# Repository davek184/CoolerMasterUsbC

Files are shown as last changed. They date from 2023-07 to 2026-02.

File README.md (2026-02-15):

# Cooler Master Novatouch Daughterboard USB-C
USB-C Daughterboard for Cooler Master Novatouch. Fits in the stock case without any changes.  Also fits Norbatouch, Masterkeys Pro S & Rapid-i.

Update 2026: This version is suprior but can be difficult to obtain so built an [alternative DIY option](https://github.com/davek184/Coolermaster-USB-C-remix)

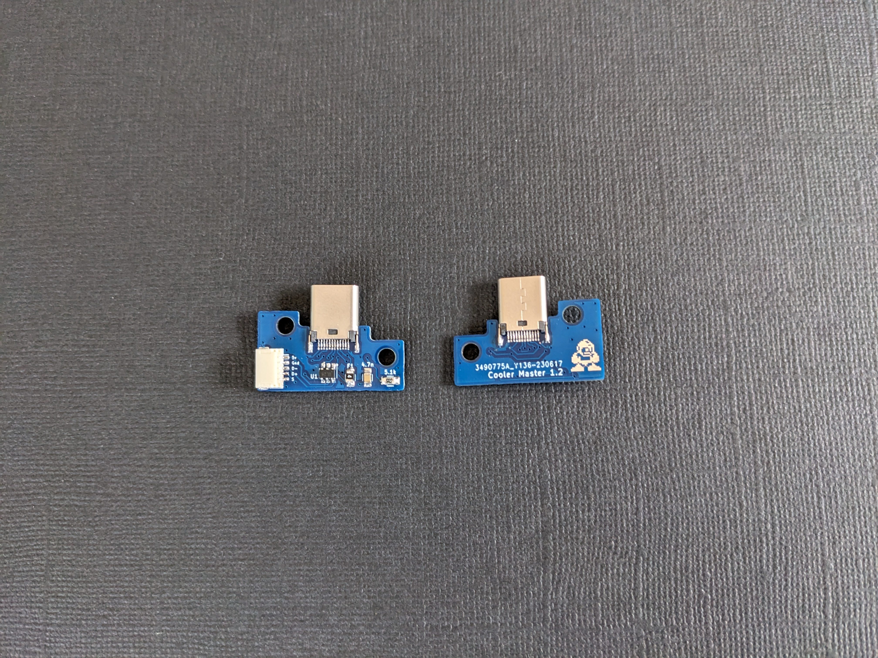
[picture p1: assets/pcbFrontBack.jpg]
PCB2


## Disclaimers
* Norbatouch compatible if using 2 m3 nuts as washers.
* Use at your own risk
* This will only give USB-C connection for the keyboard. Programmability requires a custom full PCB.

# Cable
* JST SH to PH cable
* 5 pin
* 150mm long
* Good start cable
  * https://www.aliexpress.us/item/3256804552474270.html
  * "Same Direction" so only 2 wires need to be swapped after receiving. Plug in SH (small end) first. swap the D- and D+ wire on the PH end.
  * See pinout diagram
    
## Novatouch Pinout  
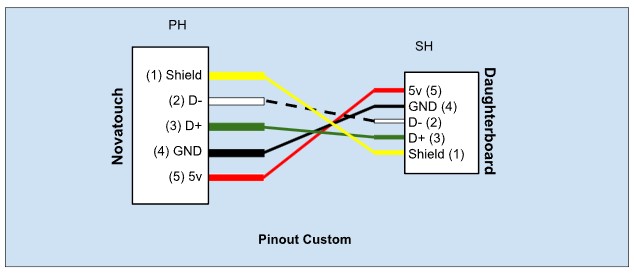
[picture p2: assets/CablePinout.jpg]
Cable

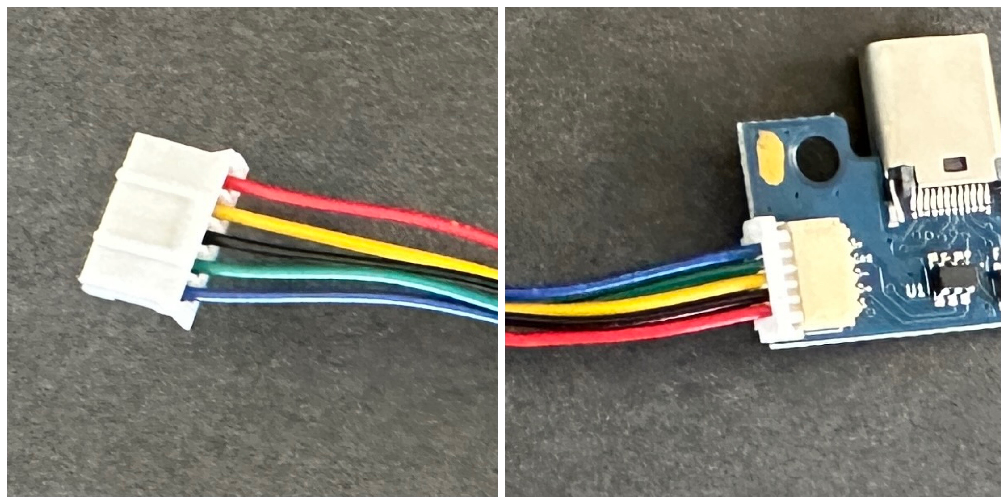
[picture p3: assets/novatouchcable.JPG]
Novatouch


## Masterkeys Pro S Pinout
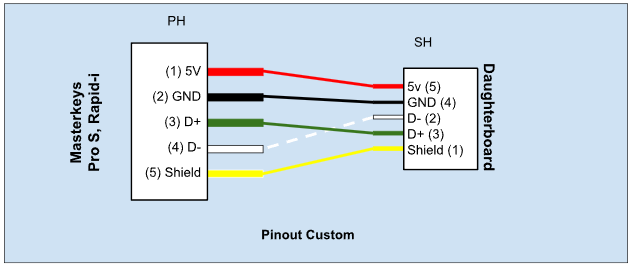
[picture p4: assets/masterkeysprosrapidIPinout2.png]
CablePros

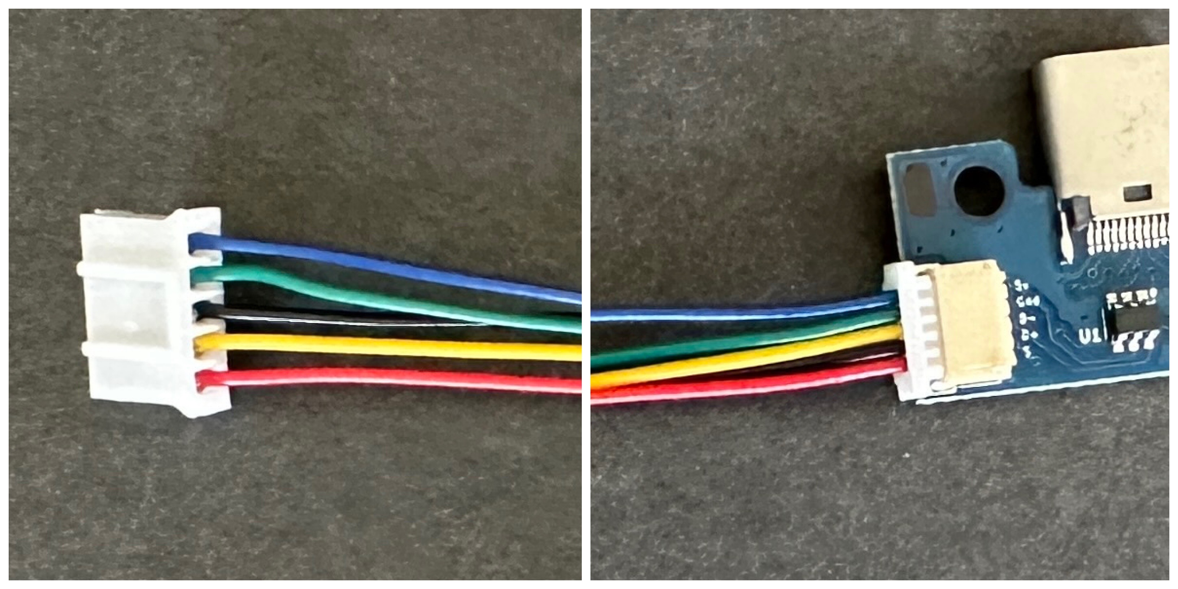
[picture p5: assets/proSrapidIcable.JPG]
ProS


## Rapid-i Pinout
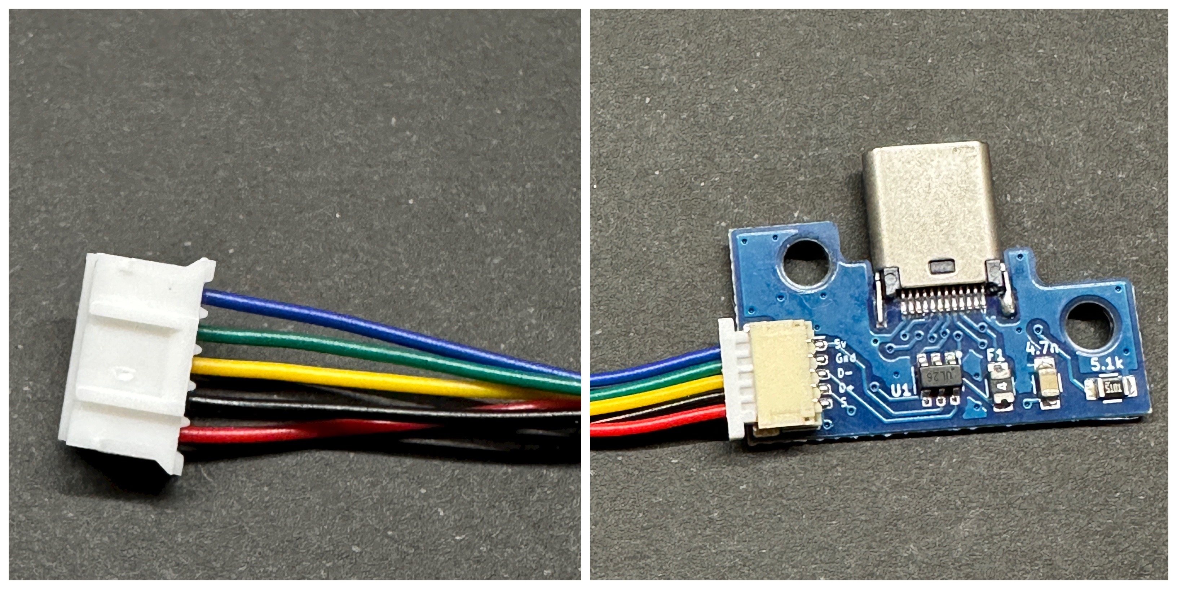
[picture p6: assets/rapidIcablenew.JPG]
Rapid-I


# Recommended Hardware

* M2 x 4mm wafer head screw/laptop screw. For mounting CMDB into stock Novatouch case. https://www.aliexpress.us/item/3256801240948974.html 
* M3 x 0.5mm 6mm hex screw, 3mm hex nut. For mounting CMDB into Norbatouch. Add o-ring or washer if still sitting too low in port opening.
* [Alternative 3d print riser](/assets/Coolermaster%20USB%20C%20Riser.stl)

# Installation Photos

<details>
 <summary>Stock Novatouch</summary>
 
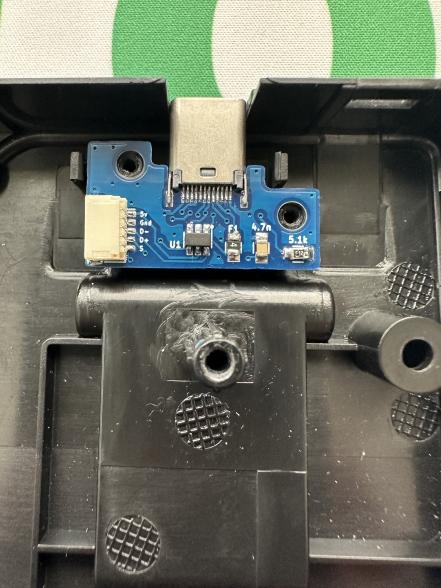
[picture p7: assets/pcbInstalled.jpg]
PCBInstalled
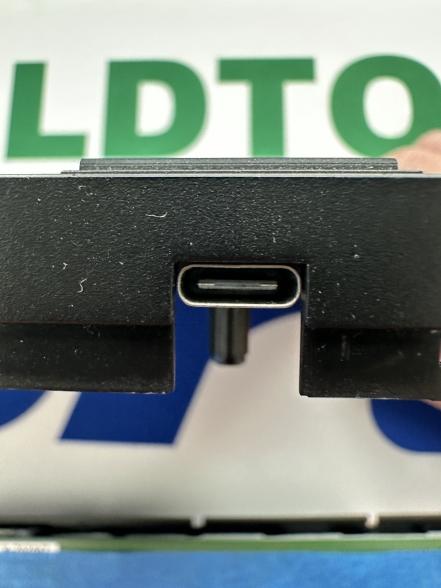
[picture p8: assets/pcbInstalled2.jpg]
PCBInstalled2
 

</details>

<details>
 <summary>Norbatouch PC</summary>

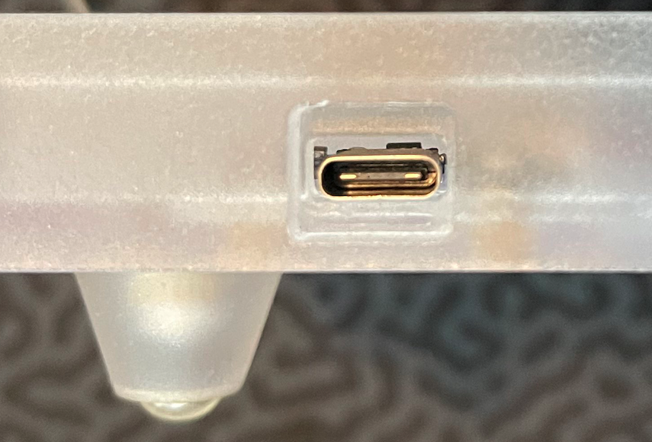
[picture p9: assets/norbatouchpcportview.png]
norbatouchpcportview
mountedinnorbatouch  withm3nuts

</details>

<details>
 <summary>Norbatouch Aluminum </summary>
 
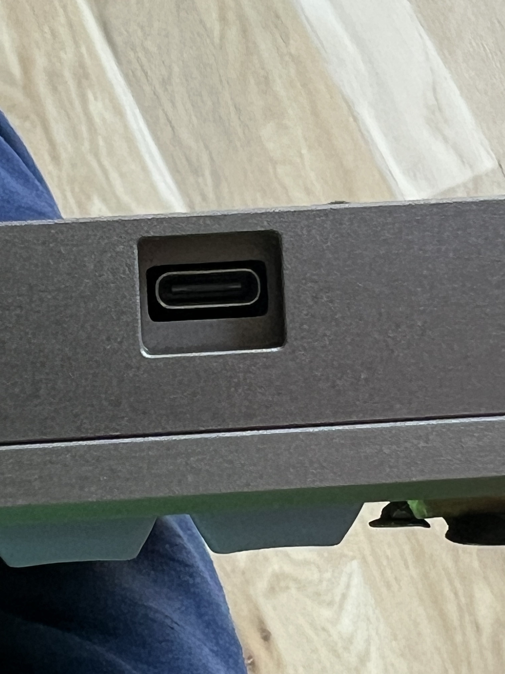
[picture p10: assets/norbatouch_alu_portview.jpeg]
norbatouch_alu_portview

 
</details>

# Revisions
* 1.1 Lets not dwell on version 1.1 other than it paved the way for version 1.2 :)
* 1.2 Worked successfully with Novatouch and Norbatouch
* 1.3 Updated design to include extra size for manufacturing along with a dummy resistor on the backside
* 1.4 Removed extra rails manufacturing because they wanted to charge extra claiming 2 designs in one file

# Manufacturing
<details>
  <summary>JLCPCB</summary>
 
  * Files: [/manufacturing](/manufacturing)
  * **1mm thick** (NOT Standard 1.6mm)
  * SMD Assembly is **Standard** not economic due to USB connector
  * Confirm Parts Placement: **Yes**
</details>
<details>
  <summary>BOM</summary>

| LCSC part # | Description | Value | Package  | Amount |
| --- | --- | ----- | --- | --- |
| C67381 | Connector (USB) | | SMD | 1 |
| C136657 | Connector(JST SH)  | 5 pin | TH | 1 |
| C7519 | ESD | | SOT23-6  | 1 |
| C261942 | Fuse | | 0805 | 1 |
| C597300 | Capacitor | 4.7nF | 0805 | 1 |
| C212411 | Resistor | 5.1K  | 0805 | 1 |
</details>

# Acknowledgments 
* [Nekotato](/https://github.com/nekotato) for validating compatibility and requesting this
* [Gouty](/https://github.com/Gouty) for initial measurements from repo: https://github.com/Gouty/CM-Keyboard_USB-Breakout
* Pixelpusher for validating compatibility in Novatouch, Masterkeys Pro S & Rapid-i.

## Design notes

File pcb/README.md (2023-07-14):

Replacement USB-C daughterboard for FC980m/c can be used with the stock case or Norbauer Heavy-9.

_Note stock case requires filing USB opening and cable is tight._

## BOM

| LCSC part # | Description | Value | Package  | Amount |
| --- | --- | ----- | --- | ---:|
| C165948 | USB | | SMD/TH | 1 |
| C160404 | Connector | | SMD | 1 |
| C528030 | Connector | | SMD | 1 |
| C261942 | Fuse	 | | SMD | 1 |
| C27834 | Resistor | 5.1 | SMD | 2 |
| C7519 | ESD | | SMD | 1 |

## Cable

This daughterboard uses a different connector then the OEM one. Suggest starting with an [Adafruit 4424 cable](https://www.adafruit.com/product/4424) so no crimping needs to be done. 

cable

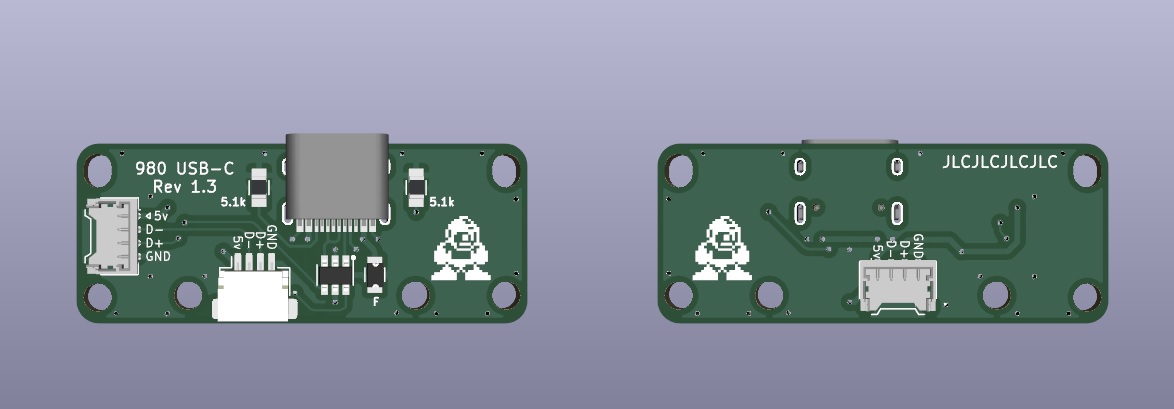
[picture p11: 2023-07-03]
pcb/assets/render.jpg

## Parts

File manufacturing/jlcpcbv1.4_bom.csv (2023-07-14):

Designator | Footprint | Quantity | Value | LCSC Part #
C1 | R_0805 | 1 | 4.7n | C597300
F1 | F_0805 | 1 | Polyfuse_Small | C261942
J1 | USB-C-SMD_C67381 | 1 | USB-C-SMD_C67381 | C67381
J2 | JST_SH_SM05B-SRSS-TB_1x05-1MP_P1.00mm_Horizontal | 1 | JST_SH_SM05B-SRSS-TB_1x05-1MP_P1.00mm_Horizontal | C136657
R2_2 | R_0805 | 1 | 5.1k | C212411
R2 | R_0805 | 1 |  | C212411
U1 | USBLC6-2SC6 | 1 | USBLC6-2SC6 | C7519

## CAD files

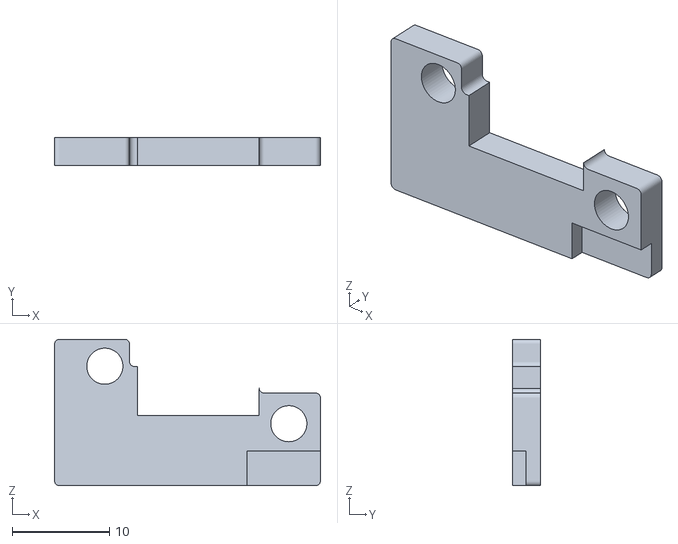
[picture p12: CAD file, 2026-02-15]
assets/Coolermaster USB C Riser.stl
27.3 x 2.90 x 15.0

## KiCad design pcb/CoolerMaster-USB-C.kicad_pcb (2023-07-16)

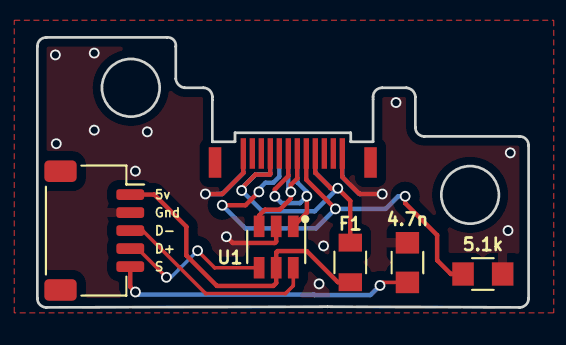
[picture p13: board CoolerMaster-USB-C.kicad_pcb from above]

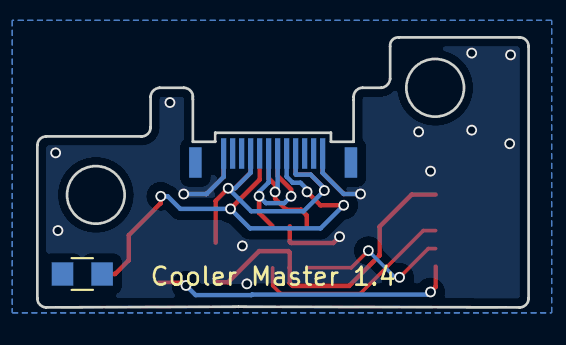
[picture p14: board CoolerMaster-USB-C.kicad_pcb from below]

Board: 2 copper layers, 27.3 x 15.0 mm, 8 parts (2 on the bottom side), 7 nets.

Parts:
C1: 4.7n; R_0805
F1: Polyfuse_Small; F_0805
G3: LOGO; MegaMan7
J1: USB-C-SMD_C67381
J2: JST_SH_SM05B-SRSS-TB_1x05-1MP_P1.00mm_Horizontal
R2: 5.1k; R_0805
R2#2: R_0805
U1: USBLC6-2SC6

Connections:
D+: J2.4, U1.4 (I/O2)
D-: J2.3, U1.6 (I/O1)
GND: C1.1, J1.1, J1.13, J2.2, R2.2, U1.2 (GND)
unnamed: J1.6, U1.1 (I/O1)
unnamed: J1.7, U1.3 (I/O2)
unnamed: J1.8, R2.1
VBUS: F1.1, F1.2, J1.4, J1.9, J2.1, U1.5 (VBUS)

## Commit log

2023-07-03 PCB files
    [CoolerMaster-USB-C.kicad_pcb, CoolerMaster-USB-C.kicad_sch]
2023-07-07 Fixed cable
2023-07-14 Revision 1.3
    [CoolerMaster-USB-C.kicad_pcb, bom.csv, designators.csv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]
2023-07-14 Add files via upload
    temporary views of mounting in Norbatouch. m3 nuts adaptation by goguma.
2023-07-16 Version 1.4
    Version 1.4
    [CoolerMaster-USB-C.kicad_pcb, bom.csv, designators.csv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]
2023-08-12 Add files via upload
    JST cable setups for Novatouch, Masterkeys Pro S / Rapid-i keyboards
2023-08-19 Update README.md
    Removed original cable because it is confusing vs the new images
2024-05-25 Add files via upload
    cable order for rapid-i is similar to masterkeys pro s except for switching the D- and D+
2026-02-15 Add alternative 3D print riser to hardware recommendations
